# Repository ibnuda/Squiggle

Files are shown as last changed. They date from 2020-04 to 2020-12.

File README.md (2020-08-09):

# Squiggle Keyboard

It's a keyboard family which based on my circumstances, preferences, and
observed usages.

Requirements:

- 5 columns per hand.
  My right pinky is almost useless.
- At most 3 keys for each side's thumb row.
  My right thumb key is almost useless.
- No numrow.
  It's harder and more cumbersome to use than a numpad on a layer.
- Split.
  Typing on single flat keyboard hurts my arms in a lot of use cases.
- Symmetric.
  Personal preferences.

This family keyboard repo will not have any of the following features:

- OLED Screen: useless.
- LEDs: useless for me and hurt my eyes.
- Rotary Encoder: useless for me.
- Hotswap: I need a commitment.
- Case for `Low Profile`: defeating the whole purpose of ***LOW*** profile.

## Screenshot

### Standard

- MX and Alps style switches.
- 34 Keys.
- 4x2u thumb keys.
- 2 Promicros.
- TRRS/TRS cable.

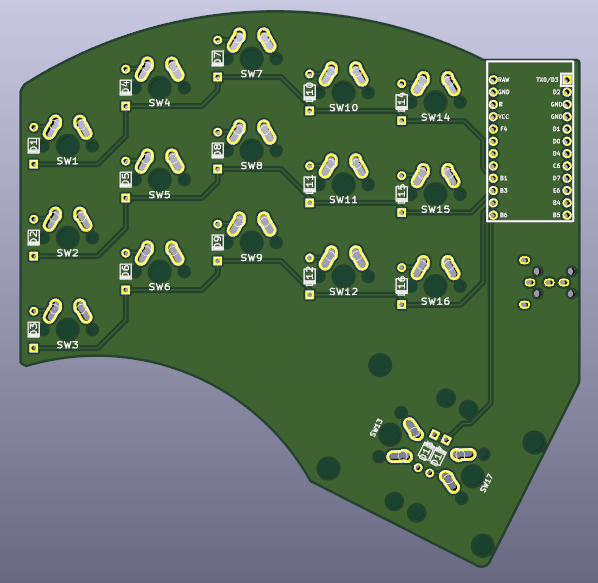
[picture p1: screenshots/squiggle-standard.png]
standard version


### Low Profile

- Dongguan Kaihua Electronics Co., Ltd (originally named Longhua Electronics)'s
  Choc style switches.
- 34 Keys.
- 4x2u thumb keys.
- 2 Promicros.
- TRRS/TRS cable.

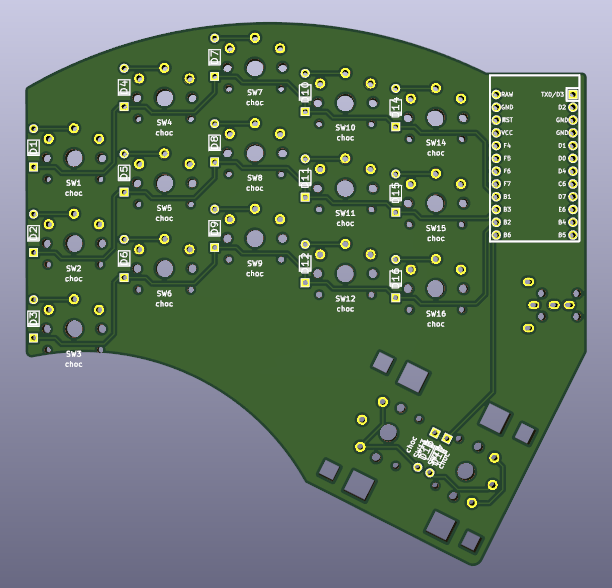
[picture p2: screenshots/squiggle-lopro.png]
low profile


### 36 Keys

- MX and Alps style switches.
- 36 Keys.
- 4x2u+2x1.25u thumb keys.
- 2 Promicros.
- TRRS/TRS cable.

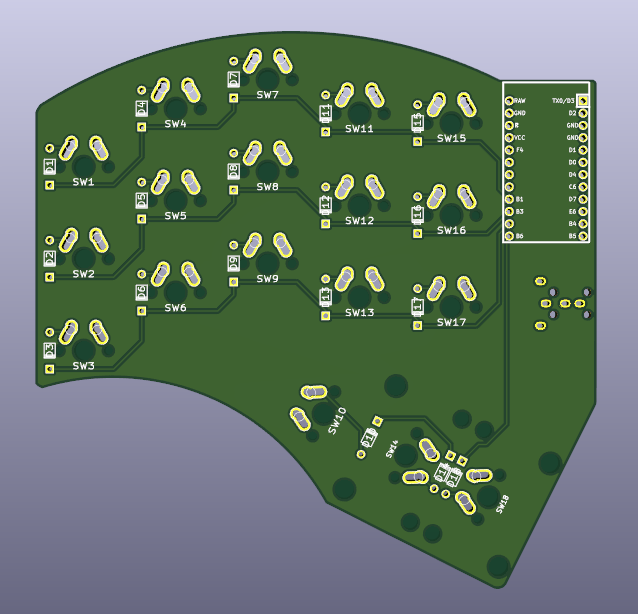
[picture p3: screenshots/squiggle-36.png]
36 keys


### Minimalist

- MX and Alps style switches.
- 34 Keys.
- 4x2u thumb keys.
- 1 Promicros.
- "Amphenol 10 wire" cable.

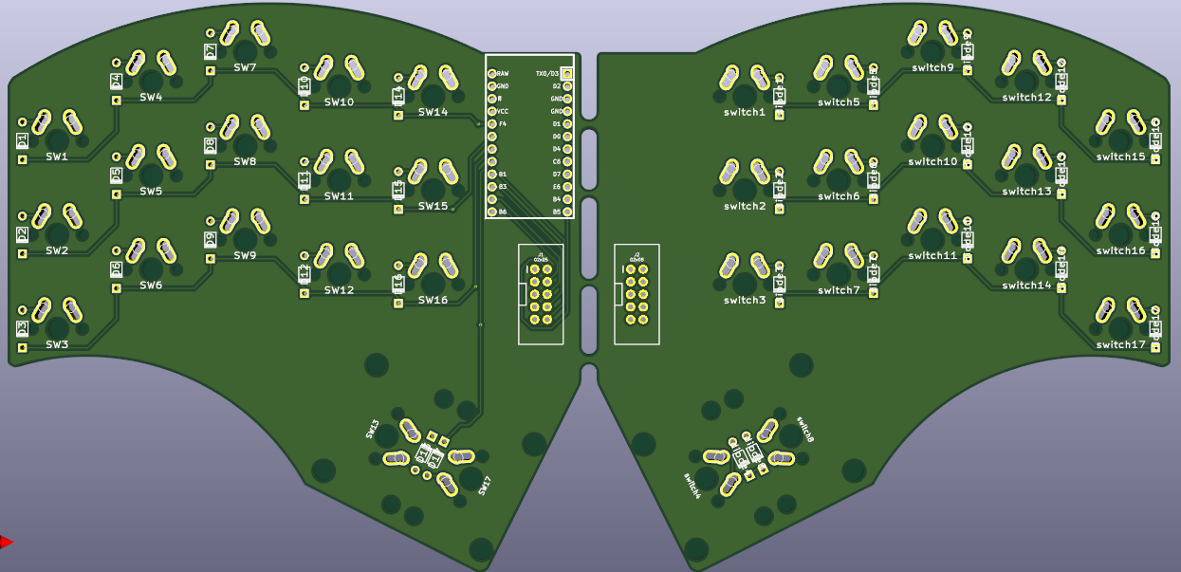
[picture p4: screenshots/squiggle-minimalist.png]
minimalist


### Goldberg

(Because it's more complex than necessary. It's just a damn keyboard.)

- MX and Alps style switches.
- 34 - 38 Keys.
- 4x2u or 8x1u thumb keys. (or anything in between)
- 2 Promicros.
- TRRS/TRS cable.

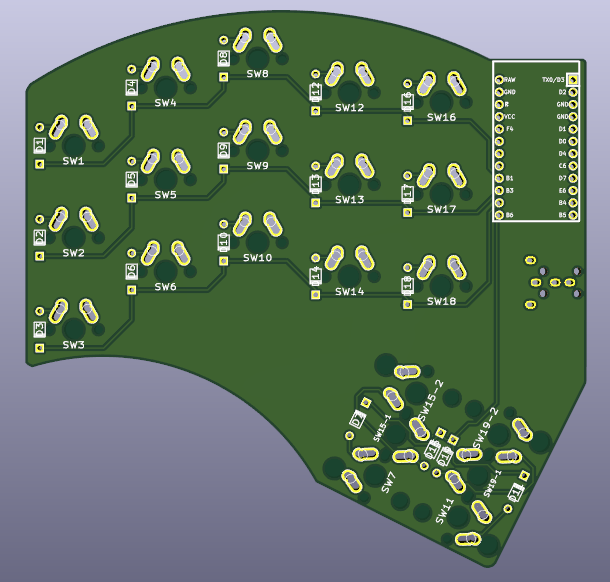
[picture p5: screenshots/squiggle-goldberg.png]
goldberg


## Confirmed Working PCBs

### Standard

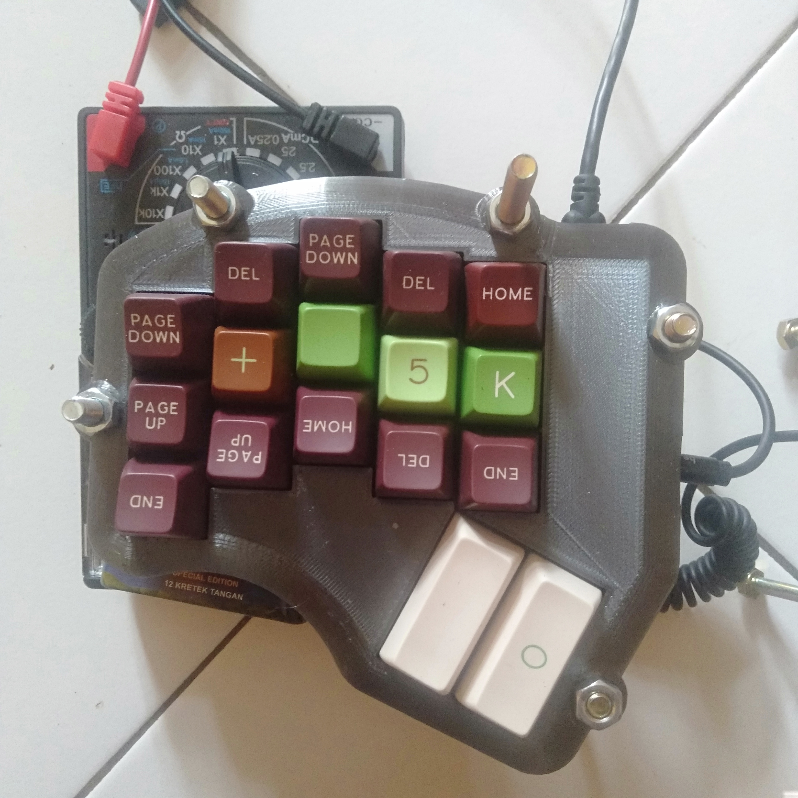
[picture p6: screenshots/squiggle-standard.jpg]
standard


Example firmware: [QMK's master branch](https://github.com/qmk/qmk_firmware/tree/master/keyboards/squiggle/keymaps/rick)

### Goldberg

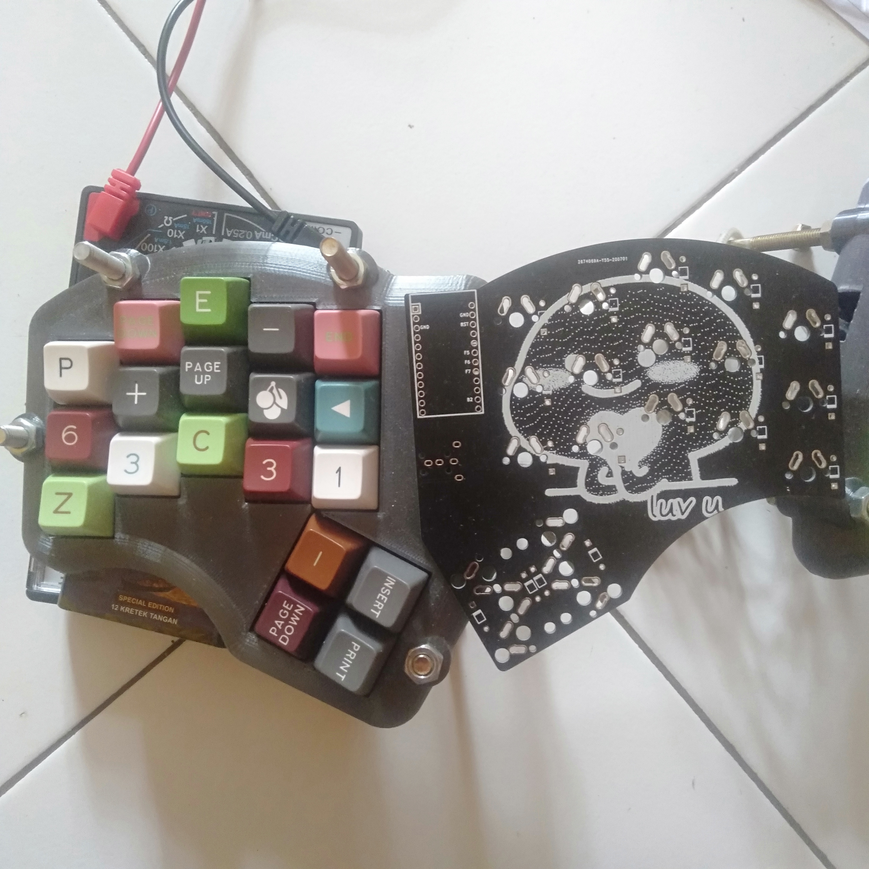
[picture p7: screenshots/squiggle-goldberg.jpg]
goldberg


Example firmware: [QMK's master branch](https://github.com/qmk/qmk_firmware/tree/master/keyboards/squiggle/keymaps/rick-complicated)

### Low Profile

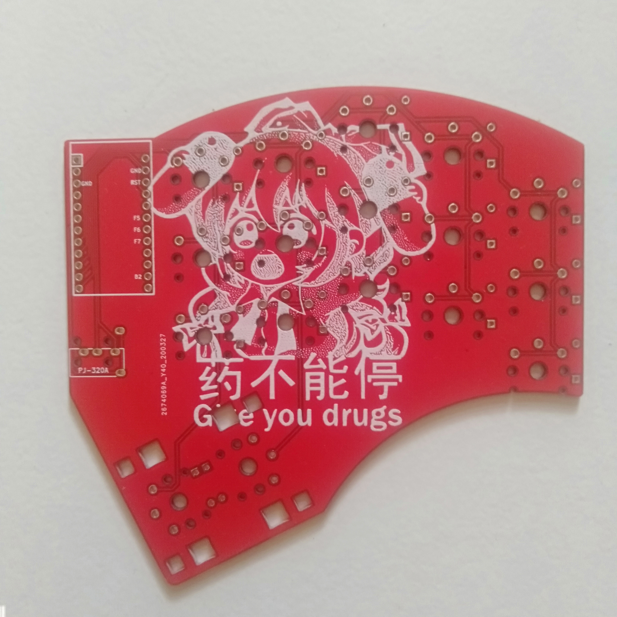
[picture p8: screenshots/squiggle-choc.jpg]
choc


Example firmware: [QMK's master branch](https://github.com/qmk/qmk_firmware/tree/master/keyboards/squiggle/keymaps/rick)

### Minimalist

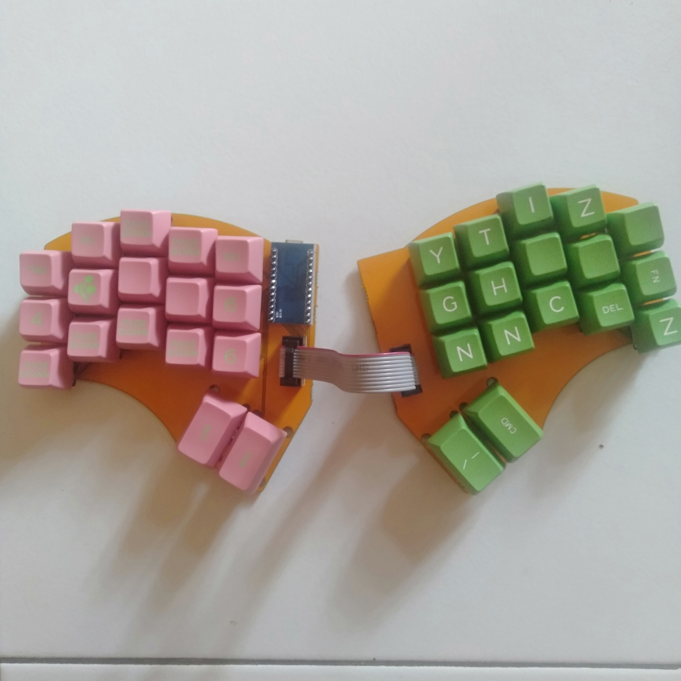
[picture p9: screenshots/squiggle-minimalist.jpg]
minimalist


Example firmware: [Ibnuda's fork](https://github.com/ibnuda/qmk_firmware/tree/squiggle-minimalist/keyboards/squiggle_minimalist/keymaps/rick)

## Disclaimer

I haven't printed some of it. But, theoretically, they should just work.
Oh, if things go wrong, I won't take any responisibilities.

## Additional Note

Any files with `mokou_*.kicad_mod` in `libs/footprints` are made by [Jokan Hiyou](https://twitter.com/jokanhiyou)
and belong to hers.
I just dither them and made them kicad footprints.

## License

GPLv3.

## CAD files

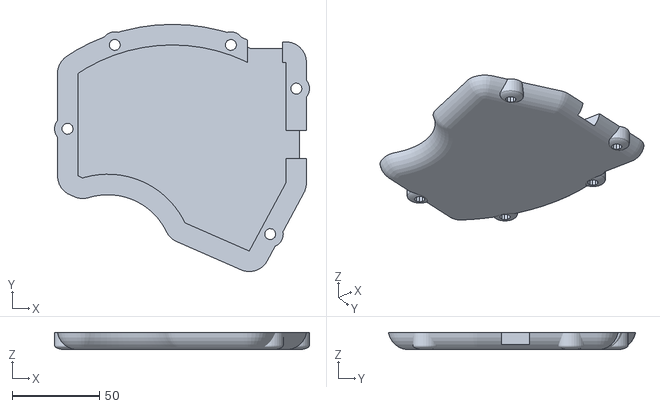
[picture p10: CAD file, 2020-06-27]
plates/fat-bottom.stl
146.0 x 141.5 x 9.93

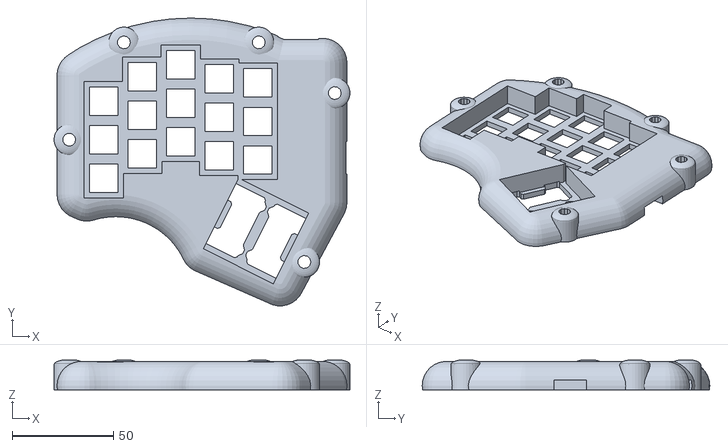
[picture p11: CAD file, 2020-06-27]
plates/fat-top.stl
146.0 x 141.9 x 14.8

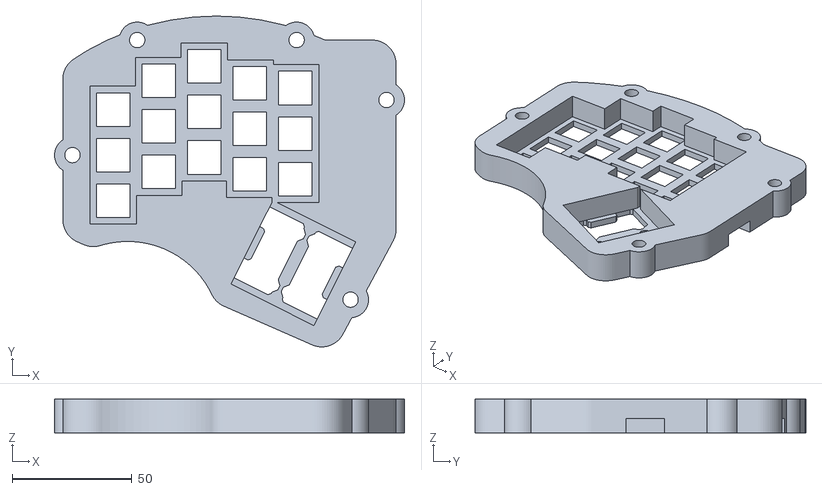
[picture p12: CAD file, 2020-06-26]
plates/another-case-switch-top.stl
146.0 x 138.0 x 14.0

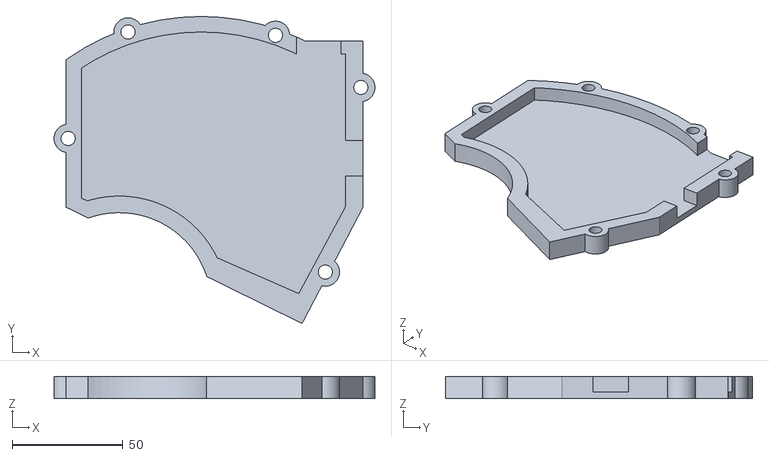
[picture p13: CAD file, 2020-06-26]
plates/case-bottom-middle.stl
144.8 x 138.5 x 10.0

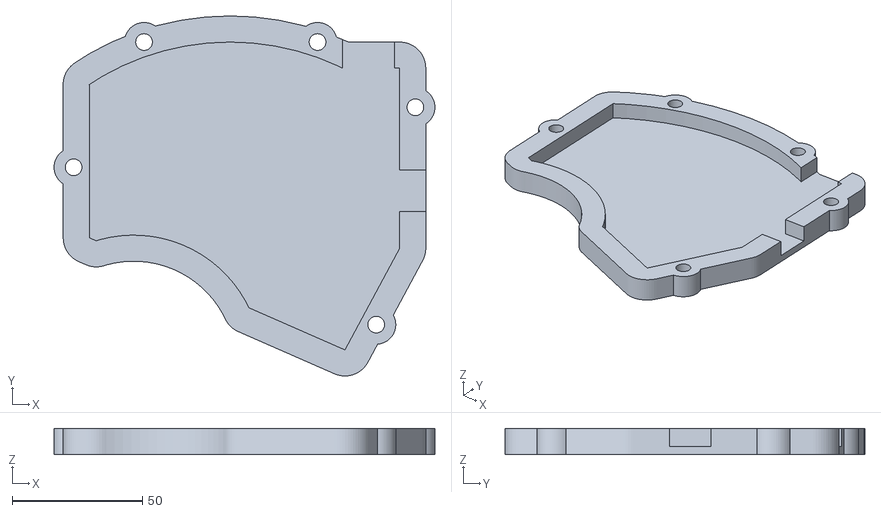
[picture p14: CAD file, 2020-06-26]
plates/another-case-bottom-middle.stl
146.0 x 138.0 x 10.0

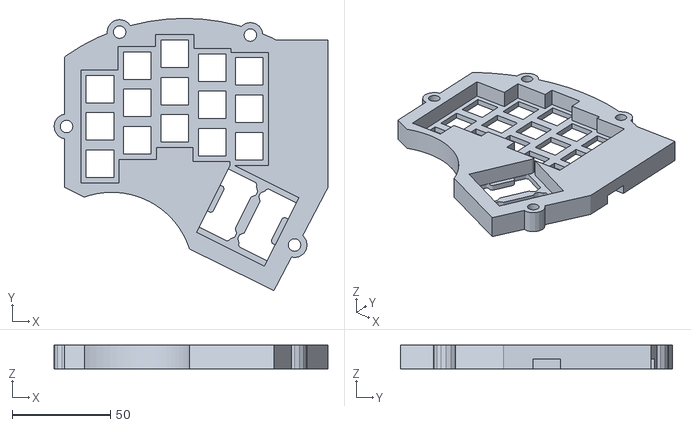
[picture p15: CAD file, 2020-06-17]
plates/case-top-switch.stl
139.4 x 138.5 x 12.0

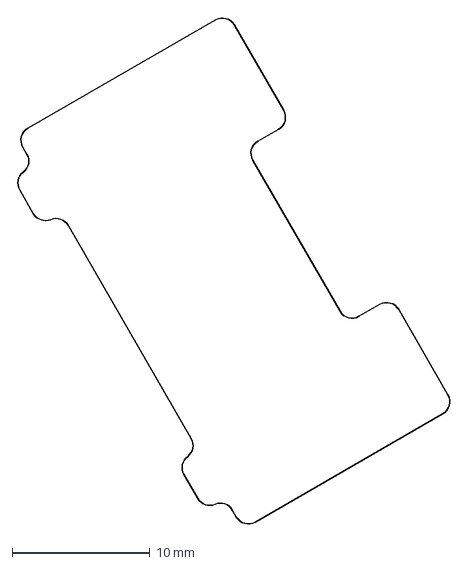
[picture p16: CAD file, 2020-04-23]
plates/2u-cutout.dxf
31.6 x 37.0 mm

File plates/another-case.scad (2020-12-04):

include <common.scad>;

$fn = 60;

bottom_thickness = 3;
middle_thickness = 8;
switch_thickness = 3;
top_thickness = 7;

use_tenting_screws = true;

is_36 = false;

is_case = true;

is_goldberg = false;

is_high = false;

module
bottom_plate()
{
    difference()
    {
        union()
        {
            offset(r = 10) shape_of_pcb();
            if (use_tenting_screws) {
                for (i = [0:len(tenting_screw_positions) - 1]) {
                    translate(tenting_screw_positions[i]) tenting_wing();
                }
            }
        }
        if (use_tenting_screws) {
            for (i = [0:len(tenting_screw_positions) - 1]) {
                translate(tenting_screw_positions[i]) tenting_hole();
            }
        } else {
            for (i = [0:len(tightening_screw_positions) - 1]) {
                translate(tightening_screw_positions[i]) tightening_hole();
            }
        }
    }
}

module
middle_plate()
{
    difference()
    {
        bottom_plate();
        shape_of_pcb();
        // promicro_trrs_space();
        white_space();
    }
}

module upper_plate(hole_width, is_switch_plate = true)
{
    difference()
    {
        bottom_plate();
        alpha_holes(hole_width);
        thumb_hole(96.6, -98.7, 153.4, is_switch_plate, hole_width, is_goldberg);
        thumb_hole(113.7, -107.3, -26.6, is_switch_plate, hole_width, is_goldberg);
        if (is_switch_plate)
        {
            // promicro_trrs_space();
            white_space();
        }
        if (is_36)
        {
            inner_thumb_hole(hole_width);
        }
    }
}

if (is_case) {
    translate([ 150, 0, 0 ]) color([ 0.4, 0.3, 0.2 ])
    {
        // linear_extrude(height = bottom_thickness) { bottom_plate(); }
    }
    translate([ 150, 0, bottom_thickness ]) color([ 0.2, 0.3, 0.2 ])
    {
        linear_extrude(height = middle_thickness) { middle_plate(); }
    }
    translate([ 0, 0, 0 ]) color([ 0.3, 0.3, 0.3 ])
    {
        // linear_extrude(height = switch_thickness) { upper_plate(14, true); }
    }
    if (is_high) {
        difference()
        {
            translate([ 0, 0, switch_thickness ]) color([ 0.5, 0.5, 0.5 ])
            {
                linear_extrude(height = top_thickness)
                {
                    upper_plate(19.5, false);
                }
            }
            translate([ 0, 0, switch_thickness ]) linear_extrude(height = 3)
            {
                promicro_trrs_space();
            }
        }
    }
} else {
    // translate([ 150, 0, 3 ]) color([ 0.2, 0.2, 0.2 ]) bottom_plate();
    // translate([ 0, 140, 3 ]) color([ 0.2, 0.2, 0.2 ]) middle_plate();
    translate([ 0, 0, 6 ]) color([ 0.2, 0.2, 0.9 ]) upper_plate(14, true);
}

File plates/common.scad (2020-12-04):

tenting_screw_positions =
    [ [ 129, -118.3 ], [ 40, -10 ], [ 106.5, -10 ], [ 13, -58 ]/*, [ 144, -35 ]*/ ];

tightening_screw_positions = [
    [ 17.5, -26, 0 ],
    [ 18.5, -88, 0 ],
    [ 81.0, -116, 0 ],
    [ 118.5, -132.5, 0 ],
    [ 139, -88.5, 0 ],
    [ 140, -56.5, 0 ],
    [ 140, -20.5, 0 ],
    [ 112.5, -17.2, 0 ],
    [ 71, -8.6, 0 ]
];

stagger = [ -39, -27, -21, -28, -30 ];

module sector(radius, angles, fn = 60)
{
    r = radius / cos(180 / fn);
    step = -360 / fn;

    points = concat(
        [[ 0, 0 ]],
        [for (a = [angles[0]:step:angles[1] - 360])[r * cos(a), r * sin(a)]],
        [[r * cos(angles[1]), r * sin(angles[1])]]);

    difference()
    {
        circle(radius, $fn = fn);
        polygon(points);
    }
}

module arc(radius, angles, width = 1, fn = 60)
{
    difference()
    {
        sector(radius + width, angles, fn);
        sector(radius, angles, fn);
    }
}

module
tenting_wing()
{
    circle(r = 7.5);
}

module
tenting_hole()
{
    circle(r = 3.2);
}

module
tightening_hole()
{
    circle(r = 1.2);
}

module
white_space()
{
    polygon(points=[
        [ 116, -5 ],
        [ 116, -77.5 ],
        [ 150, -94.5 ],
        [ 150, -10 ]
    ]);
}

module
promicro_space()
{
    // promicro space.
    polygon(points = [
        [ 116, -5 ],
        [ 136, -5 ],
        [ 136, -56 ],
        [ 116, -56 ],
    ]);
}

module
trrs_space()
{
    polygon(points = [
        [ 155, -75 ],
        [ 155, -59 ],
        [ 122, -59 ],
        [ 122, -75 ],
    ]);

}

module
idc_space()
{
    polygon(points = [
        [ 122, -59 ],
        [ 133, -59 ],
        [ 133, -81 ],
        [ 122, -81 ],
    ]);
}

module alpha_holes(width = 14)
{
    for (j = [0:2]) {
        for (i = [0:4]) {
            translate([ (30 + i * 19), (stagger[i] - j * 19), 0 ])
            {
                square(size = [ width, width ], center = true);
            }
        }
    }
}

module
inner_thumb_hole(width = 14)
{
    translate([ 79.57, -90.06 ])
    {
        rotate([ 0, 0, 63.4 ])
        {
            square(size = [ width, width ], center = true);
        }
    }
}

module
thumb_imported_from_file()
{
    translate([ 7, -6.3, 0 ])
    {
        rotate([ 0, 0, -30 ]) { import("2u-cutout.dxf"); }
    }
}

module
thumb_two_u()
{
    union()
    {
        translate([ 0, 9.5, 0 ]) { square(size = [ 14, 14 ], center = true); }
        translate([ 0, -9.5, 0 ]) { square(size = [ 14, 14 ], center = true); }
    }
}

module thumb_hole(x, y, rotation, is_switch_plate = true, hole_width = 14, is_goldberg = false)
{
    translate([ x, y, 0 ])
    {
        rotate([ 0, 0, rotation ])
        {
            if (is_switch_plate) {
                if (is_goldberg) {
                    thumb_two_u();
                } else {
                    thumb_imported_from_file();
                }
            } else {
                square(size = [ hole_width, hole_width * 2 ], center = true);
            };
        }
    }
}

module
shape_of_pcb()
{
    upper_angles = [ 63.7, 123.5 ];
    lower_angles = [ 15, 112 ];
    difference()
    {
        union()
        {
            translate([ 73, -108 ]) sector(98, upper_angles, 72);
            polygon(points = [
                [ 19, -26.4 ],
                [ 19, -85 ],
                [ 117, -128 ],
                [ 138, -89 ],
                [ 138, -20 ],
                [ 116, -20 ],
            ]);
        }
        translate([ 36, -133 ]) sector(49, lower_angles, 75);
    }
}

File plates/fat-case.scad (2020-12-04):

include <common.scad>

// when you don't use 2x2u for the thumbkey.
is_goldberg = false;
// when you use the minimalist variant.
is_minimalist = true;

bottom_plate_thickness = 5;
pcb_space_thickness = is_goldberg ? 4 : 6;
bottom_pcb_thickness = bottom_plate_thickness + pcb_space_thickness;
switch_plate_thickness = is_goldberg ? 5 : 3;
bottom_pcb_switch_thickness = bottom_pcb_thickness + switch_plate_thickness;

promicro_trrs_height = 12;
idc_space_height = 25;

movement = is_goldberg ? 3 : 5;

module
almost_flat_sphere()
{
    resize([ 15, 15, 4.5 ]) translate([ 0, 0, -75 ]) sphere(r = 75);
}

module
tenting_cylinder()
{
    hull()
    {
        translate([ 0, 0, 25 ]) almost_flat_sphere();
        translate([ 0, 0, 4 ]) almost_flat_sphere();
    }
}

module
base_case()
{
    difference()
    {
        union()
        {
            minkowski()
            {
                translate([ 0, 0, 12 ]) sphere(r = 12);
                linear_extrude(height = 0.1) shape_of_pcb();
            }
            for (i = [0:len(tenting_screw_positions) - 1]) {
                translate(tenting_screw_positions[i]) tenting_cylinder();
            }
        }

        for (i = [0:len(tenting_screw_positions) - 1]) {
            translate([ 0, 0, -1 ]) linear_extrude(height = (12 * 2.5))
                translate(tenting_screw_positions[i]) tenting_hole();
        }
    }
}

module case ()
{
    difference()
    {
        base_case();
        translate([ 0, 0, bottom_plate_thickness ]) linear_extrude(height = pcb_space_thickness) shape_of_pcb();
        translate([ 0, 0, bottom_plate_thickness ]) linear_extrude(height = promicro_trrs_height) promicro_space();
        if (is_minimalist) {
            translate([ 0, 0, bottom_plate_thickness ]) linear_extrude(height = idc_space_height) idc_space();
        } else {
            translate([ 0, 0, bottom_plate_thickness ]) linear_extrude(height = promicro_trrs_height) trrs_space();
        }
        translate([ 0, 0, bottom_pcb_thickness ]) linear_extrude(height = 5) alpha_holes(14);
        translate([ 0, 0, bottom_pcb_thickness ]) linear_extrude(height = 5) thumb_hole(96.6, -98.7, 153.4, true, 14, is_goldberg);
        translate([ 0, 0, bottom_pcb_thickness ]) linear_extrude(height = 5) thumb_hole(113.7, -107.3, -26.6, true, 14, is_goldberg);
        translate([ 0, 0, bottom_pcb_switch_thickness ]) linear_extrude(height = 23) alpha_holes(19.5);
        translate([ 0, 0, bottom_pcb_switch_thickness ]) linear_extrude(height = 23) thumb_hole(96.6, -98.7, 153.4, false, 19.5, is_goldberg);
        translate([ 0, 0, bottom_pcb_switch_thickness ]) linear_extrude(height = 23) thumb_hole(113.7, -107.3, -26.6, false, 19.5, is_goldberg);
    }
}

// bottom case.
intersection()
{
    case();
    translate([150, -150, movement]) {
        cube(size = [400, 400, 12 ], center = true);
    }
}

// top case.
translate([160, 0, -bottom_pcb_thickness]) {
    difference()
    {
        color("navy")case();
        translate([150, -150, movement]) {
            cube(size = [400, 400, 12 ], center = true);
        }
    }
}

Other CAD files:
plates/standard-case.scad

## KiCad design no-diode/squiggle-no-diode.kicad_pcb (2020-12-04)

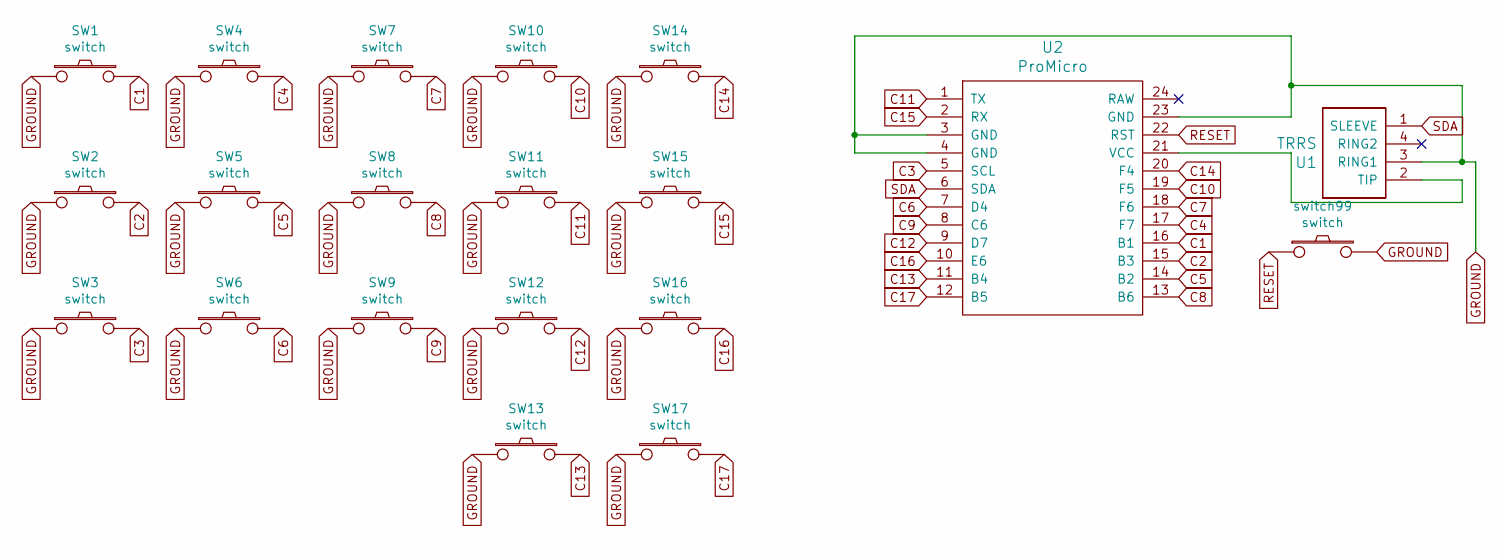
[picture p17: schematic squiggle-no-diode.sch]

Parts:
SW1, SW2, SW3, SW4, SW5, SW6, SW7, SW8, SW9, SW10, SW11, SW12, SW14, SW15, SW16: switch; 1u-dual
SW13, SW17: switch; 2u-dual
U1: TRRS; trrs
U2: ProMicro; promicro
switch99: switch; SW_PUSH_6mm_H4.3mm

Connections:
C1: SW1.2, U2.16 (B1)
C2: SW2.2, U2.15 (B3)
C3: SW3.2, U2.5 (SCL)
C4: SW4.2, U2.17 (F7)
C5: SW5.2, U2.14 (B2)
C6: SW6.2, U2.7 (D4)
C7: SW7.2, U2.18 (F6)
C8: SW8.2, U2.13 (B6)
C9: SW9.2, U2.8 (C6)
C10: SW10.2, U2.19 (F5)
C11: SW11.2, U2.1 (TX)
C12: SW12.2, U2.9 (D7)
C13: SW13.2, U2.11 (B4)
C14: SW14.2, U2.20 (F4)
C15: SW15.2, U2.2 (RX)
C16: SW16.2, U2.10 (E6)
C17: SW17.2, U2.12 (B5)
GROUND: SW1.1, SW2.1, SW3.1, SW4.1, SW5.1, SW6.1, SW7.1, SW8.1, SW9.1, SW10.1, SW11.1, SW12.1, SW13.1, SW14.1, SW15.1, SW16.1, SW17.1, U1.3 (RING1), U2.3 (GND), U2.4 (GND), U2.23 (GND), switch99.2
unnamed: U1.2 (TIP), U2.21 (VCC)
RESET: U2.22 (RST), switch99.1
SDA: U1.1 (SLEEVE), U2.6 (SDA)

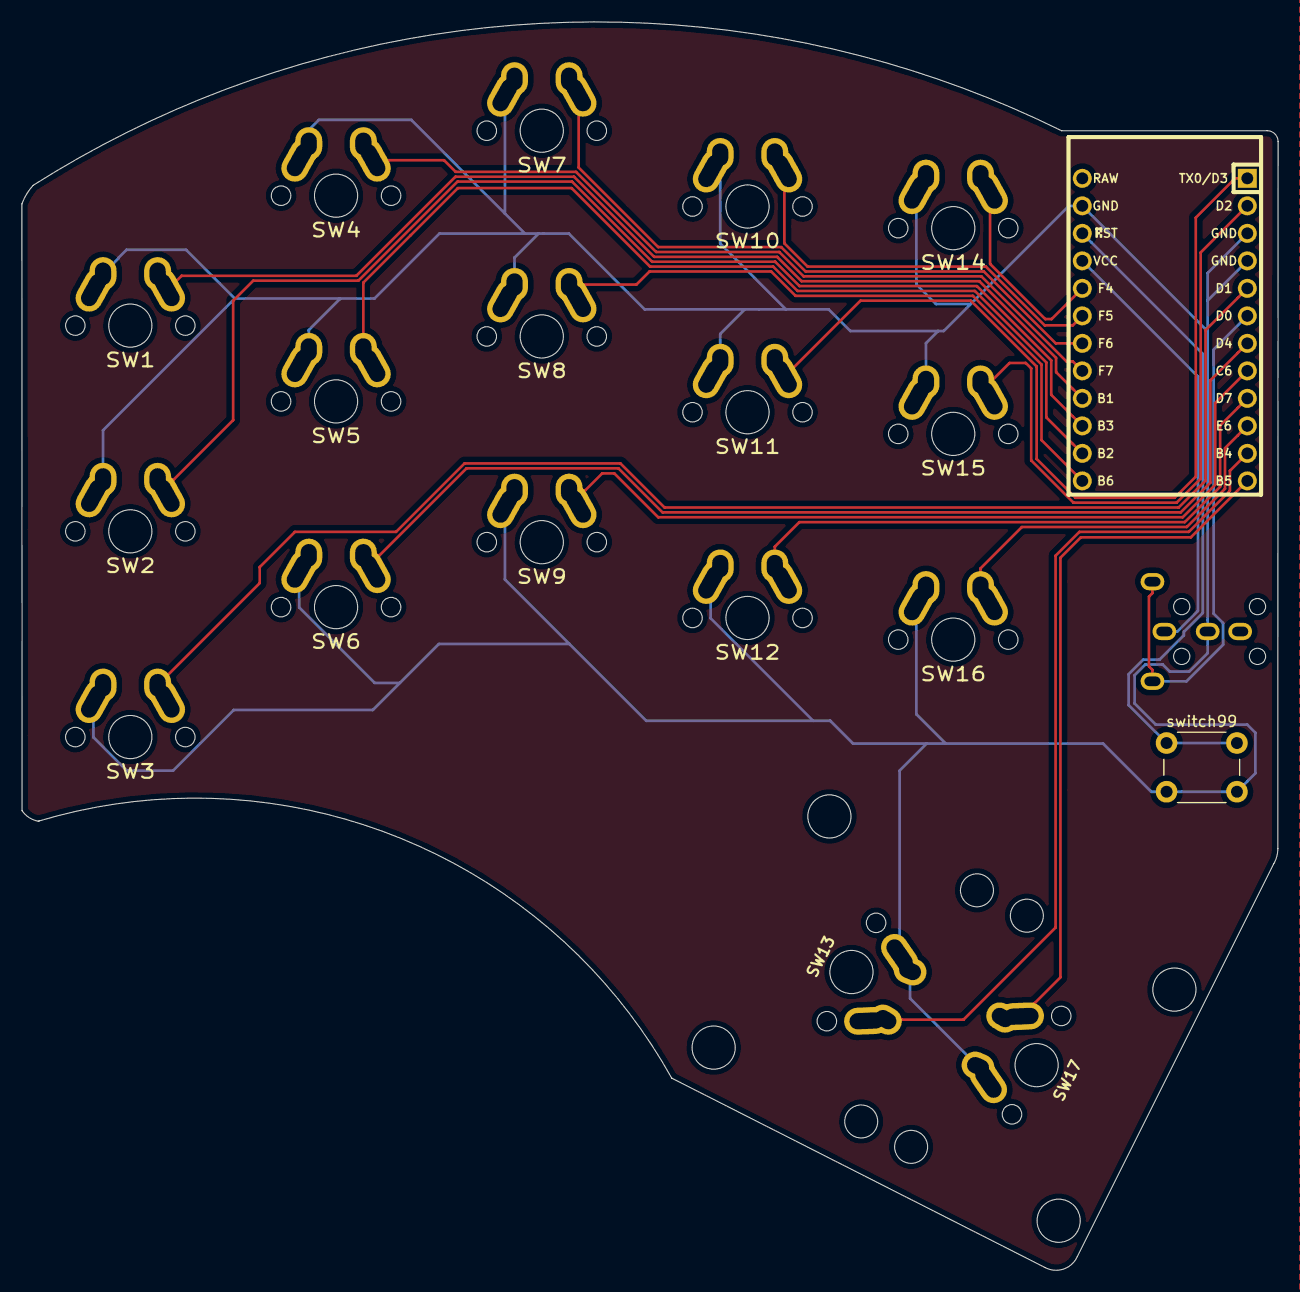
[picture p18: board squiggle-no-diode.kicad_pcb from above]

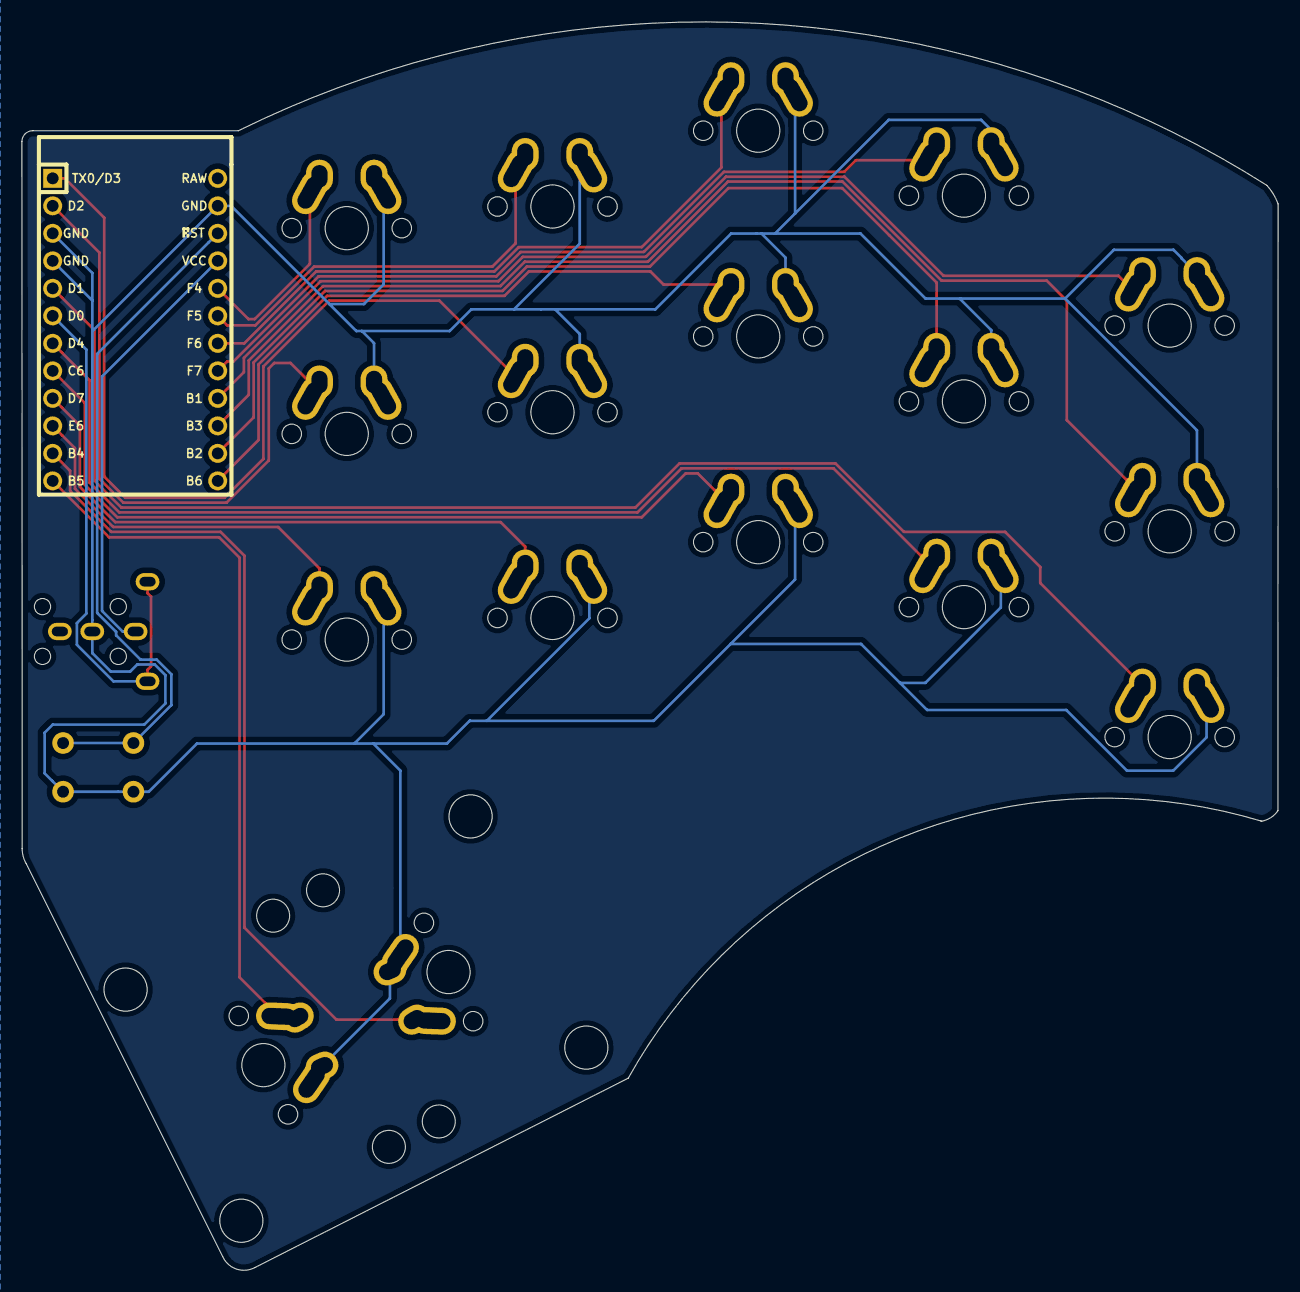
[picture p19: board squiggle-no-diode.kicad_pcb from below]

Board: 2 copper layers, 116.0 x 115.3 mm, 20 parts (2 on the bottom side), 21 nets.

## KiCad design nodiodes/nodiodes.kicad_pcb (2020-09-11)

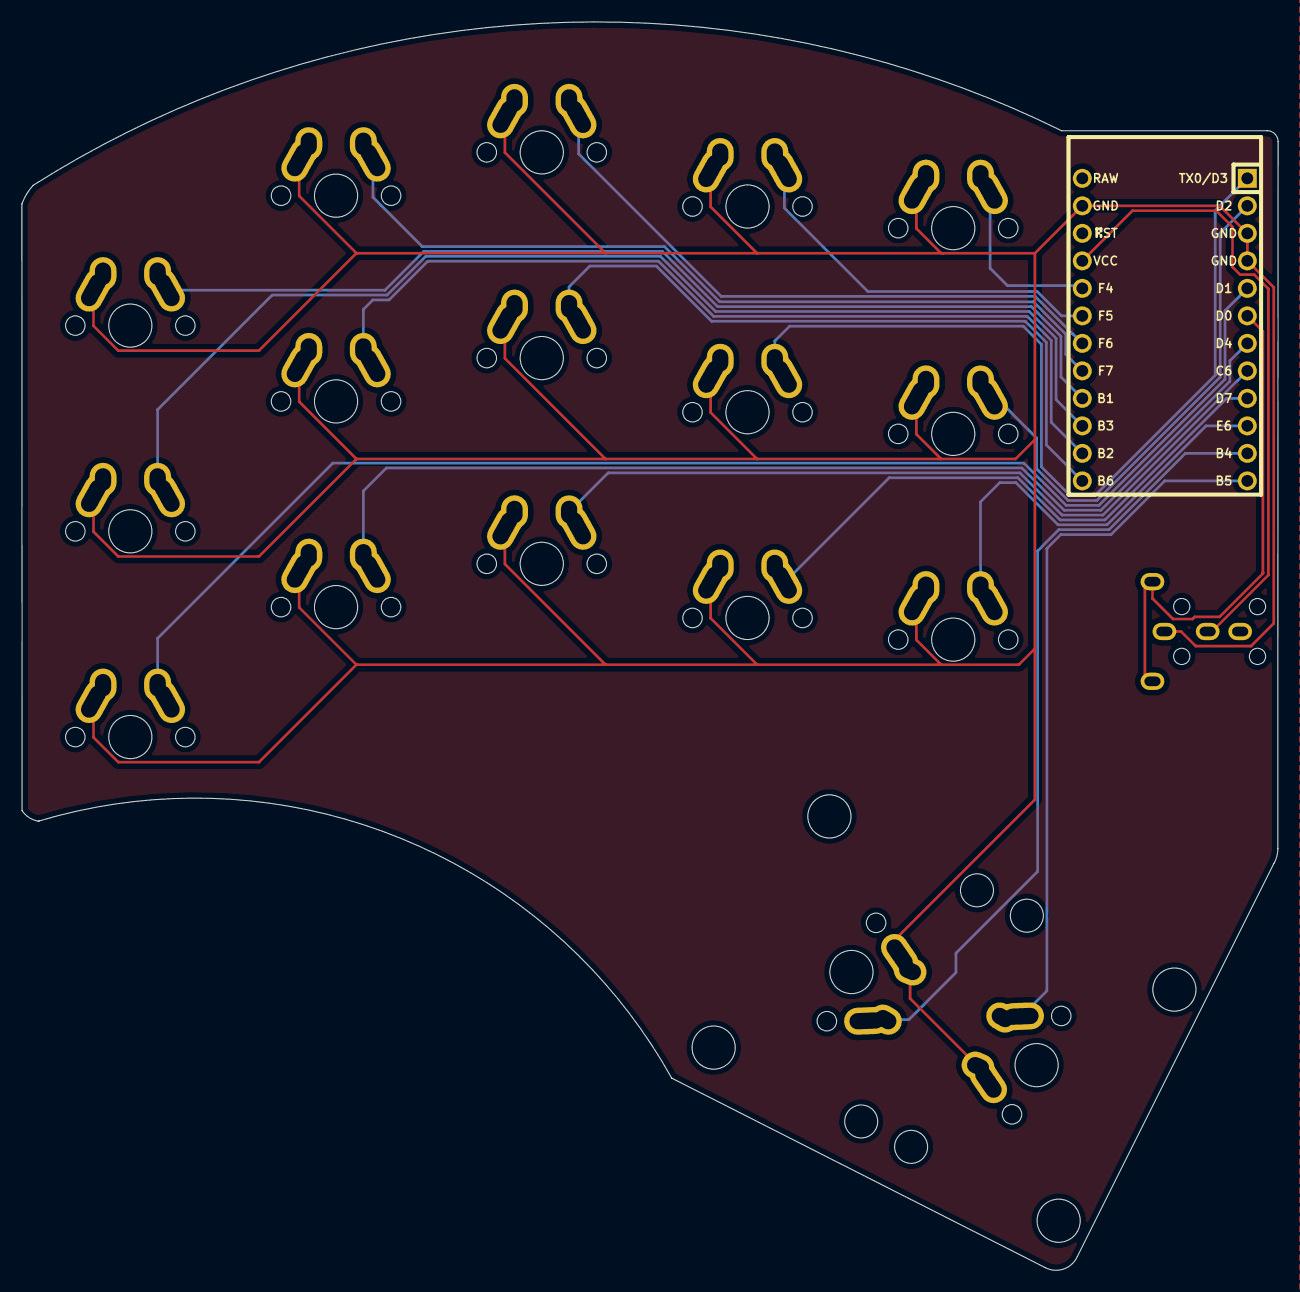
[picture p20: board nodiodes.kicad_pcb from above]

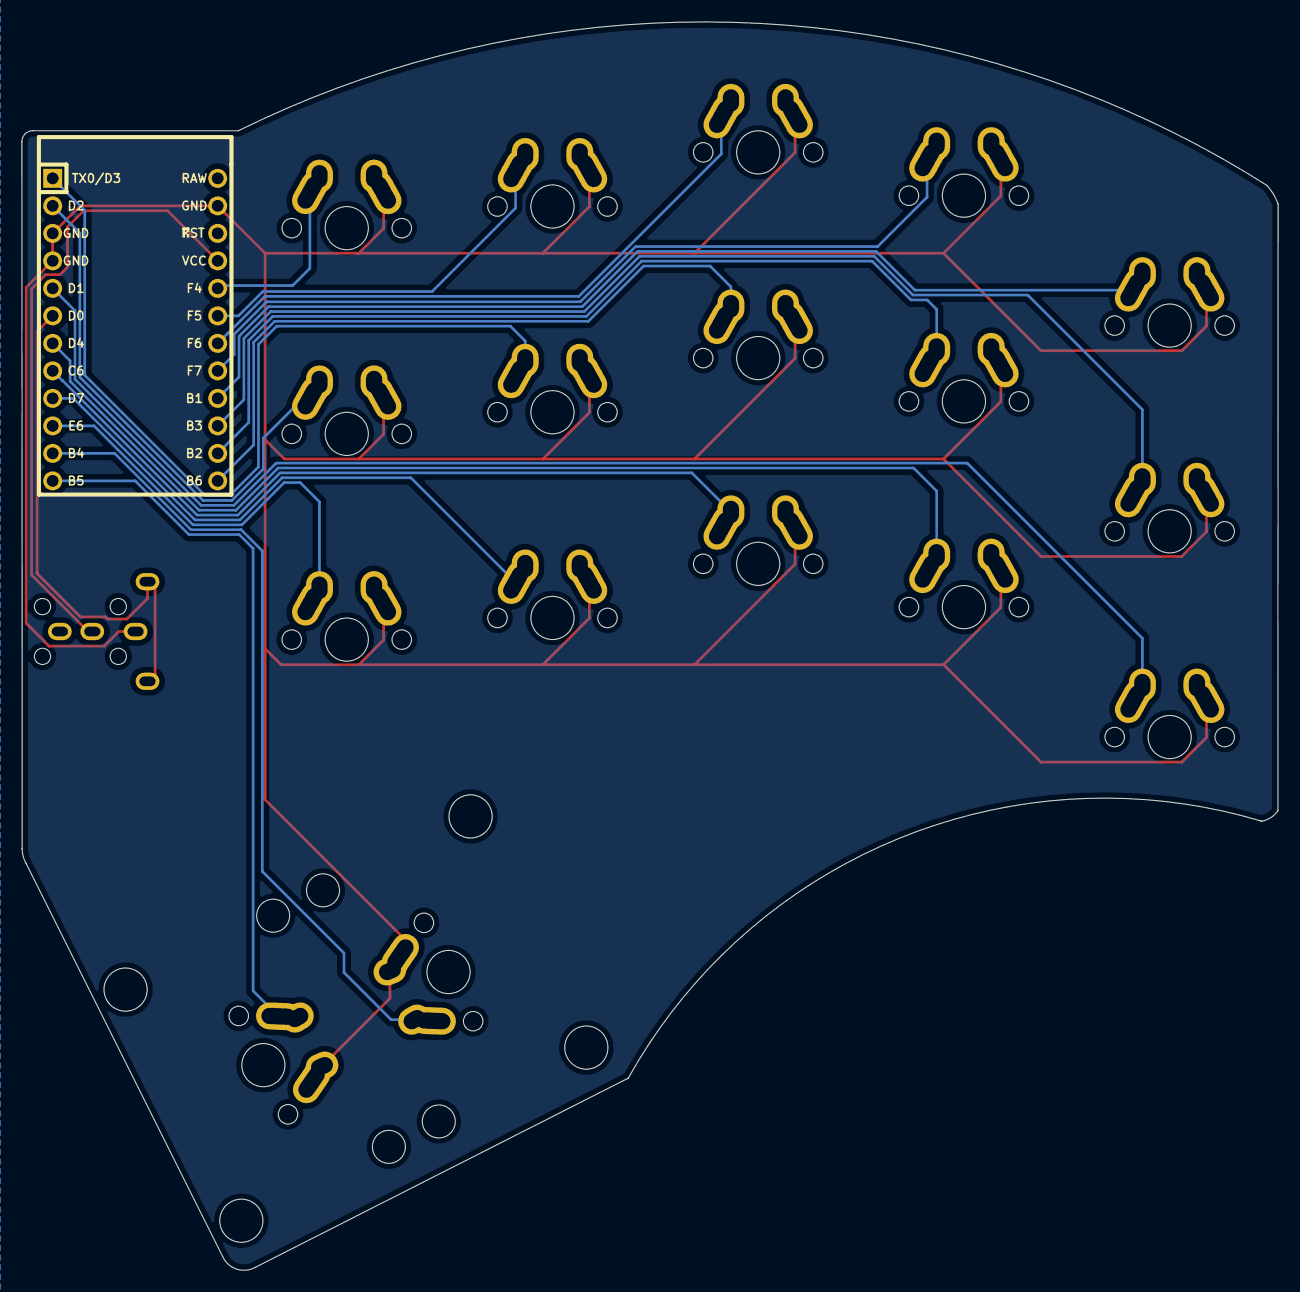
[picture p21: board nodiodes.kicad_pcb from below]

Board: 2 copper layers, 116.0 x 115.3 mm, 19 parts (2 on the bottom side), 20 nets.

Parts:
U1: trrs
U2: promicro
switch1, switch2, switch3, switch4, switch5, switch6, switch7, switch8, switch9, switch10, switch11, switch12, switch13, switch14, switch15: switch; 1u-dual
switch16, switch17: switch; 2u-dual

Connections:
GND: U1.2, U2.3, U2.4, U2.23, switch1.1, switch2.1, switch3.1, switch4.1, switch5.1, switch6.1, switch7.1, switch8.1, switch9.1, switch10.1, switch11.1, switch12.1, switch13.1, switch14.1, switch15.1, switch16.1, switch17.1
I11: U2.19, switch4.2
I12: U2.1, switch9.2
I13: U2.9, switch14.2
I21: U2.20, switch5.2
I22: U2.2, switch10.2
I23: U2.10, switch15.2
M1: U2.18, switch3.2
M2: U2.13, switch8.2
M3: U2.8, switch13.2
P1: U2.16, switch1.2
P2: U2.15, switch6.2
P3: U2.5, switch11.2
R1: U2.17, switch2.2
R2: U2.14, switch7.2
R3: U2.7, switch12.2
SDA: U1.1, U2.6
T1: U2.11, switch16.2
T2: U2.12, switch17.2
VCC: U1.3, U2.21

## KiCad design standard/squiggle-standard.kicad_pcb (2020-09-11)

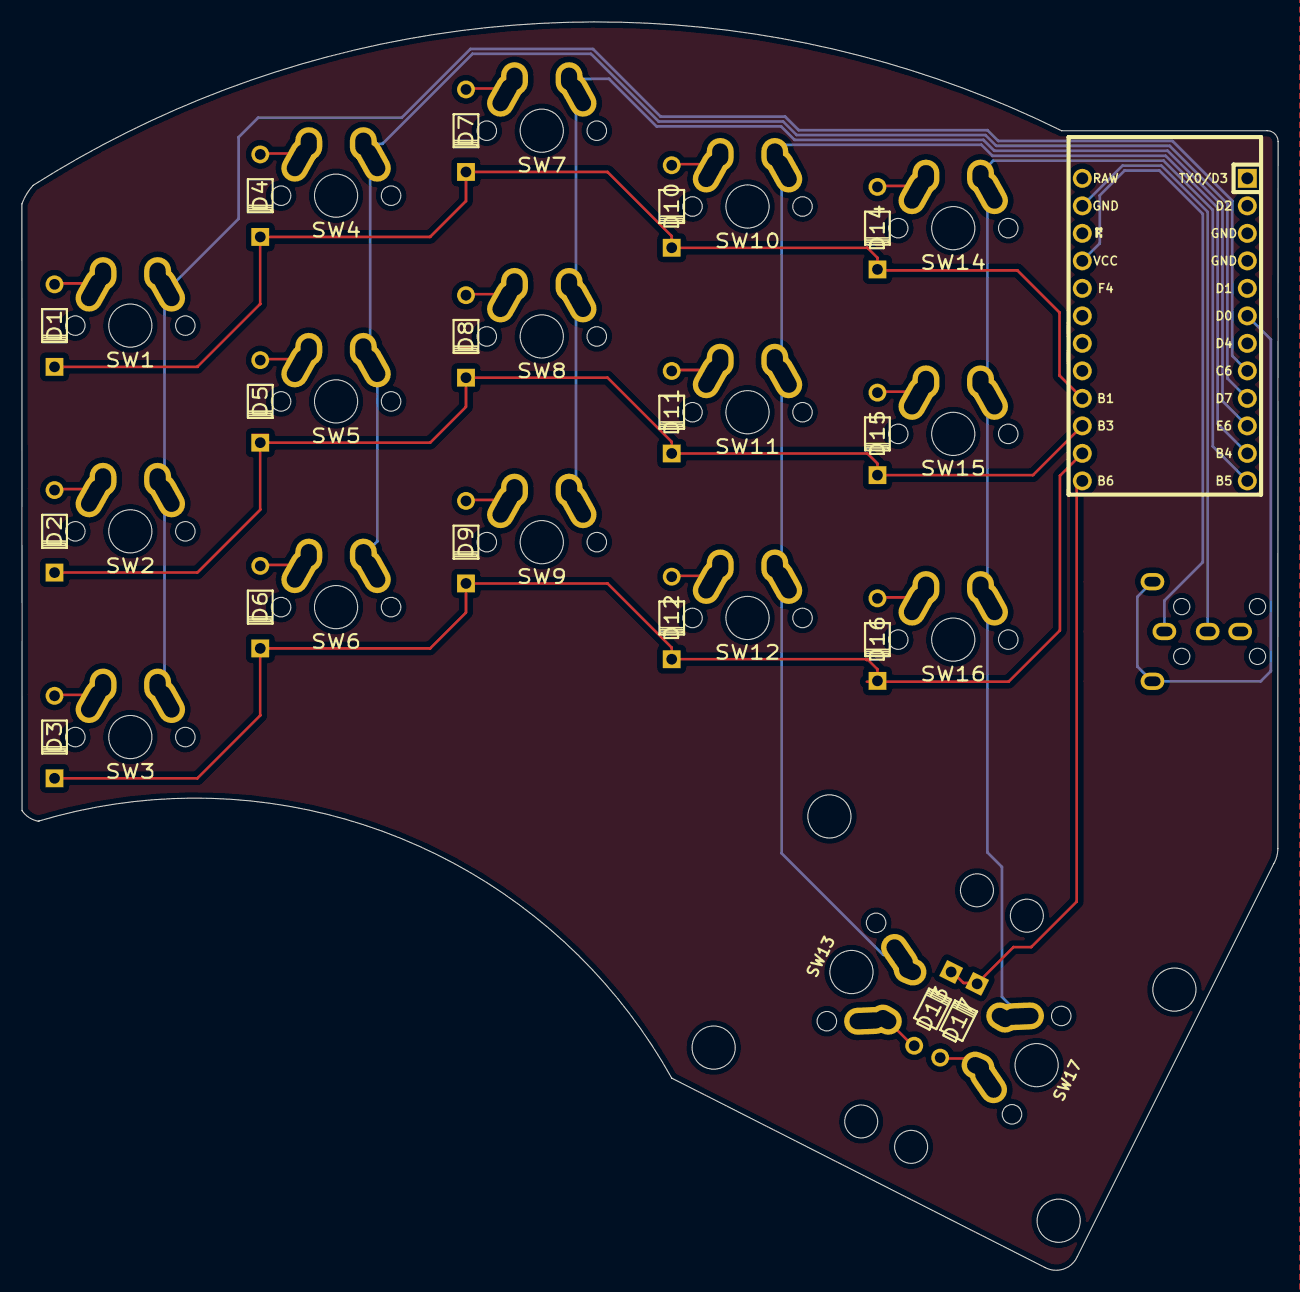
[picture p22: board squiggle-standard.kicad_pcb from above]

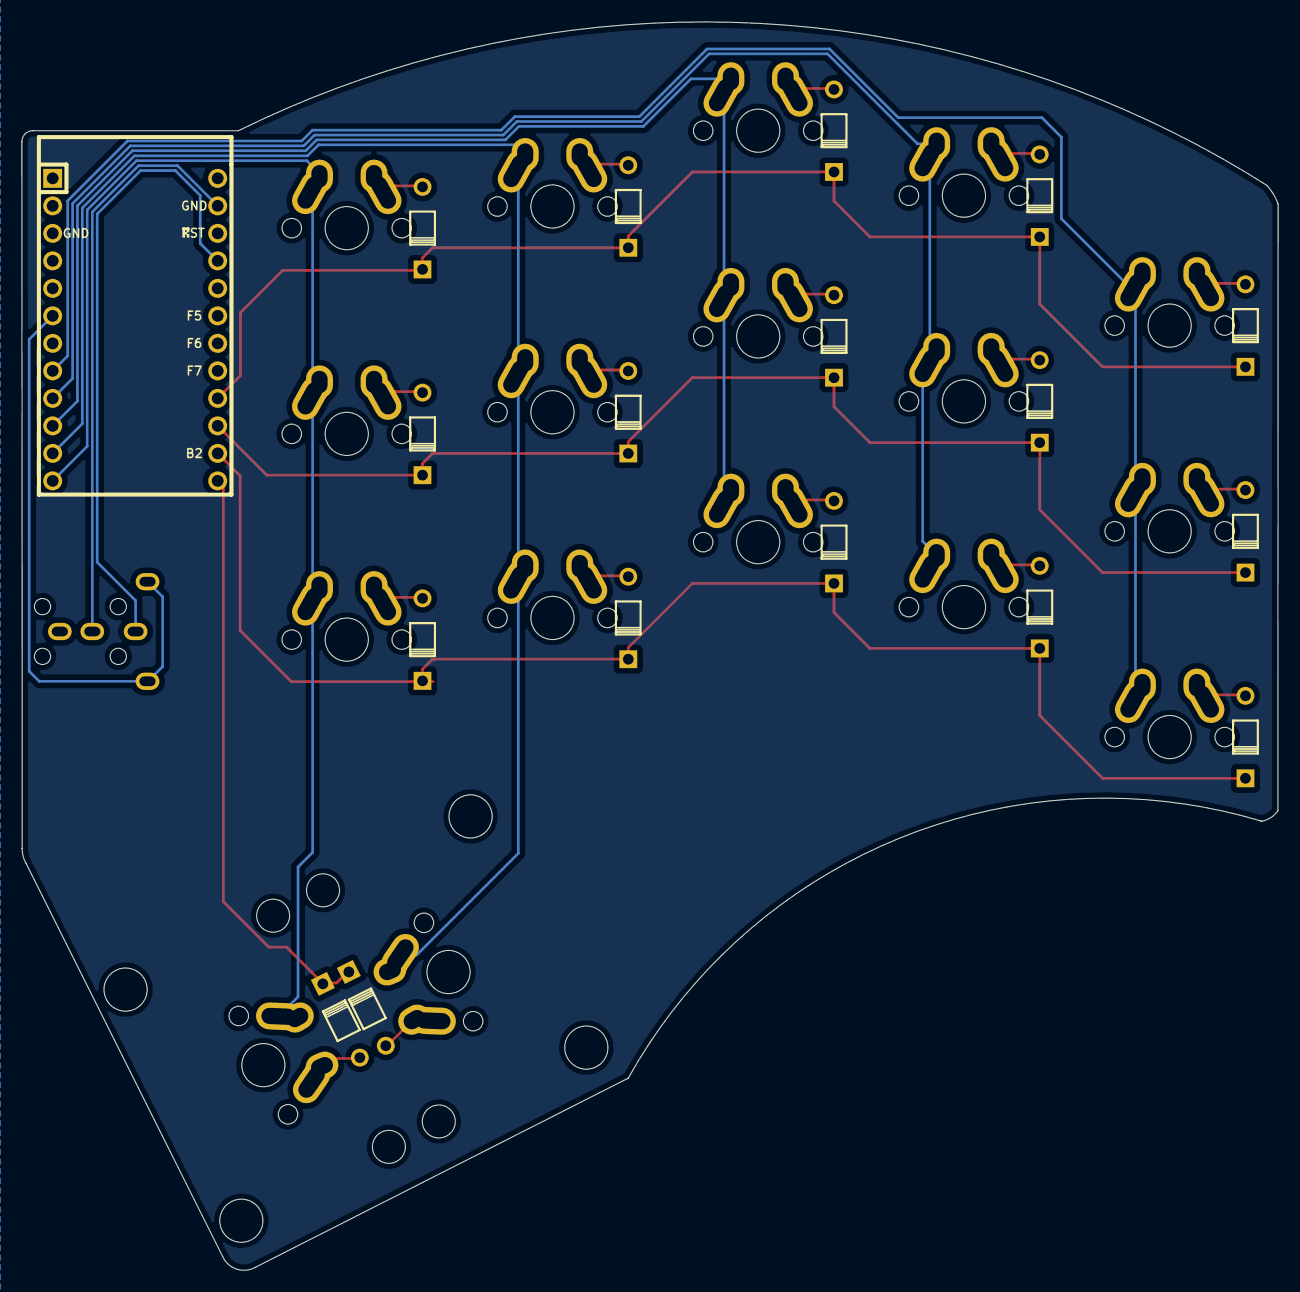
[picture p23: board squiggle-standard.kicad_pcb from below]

Board: 2 copper layers, 116.0 x 115.3 mm, 36 parts (2 on the bottom side), 29 nets.

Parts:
D1, D2, D3, D4, D5, D6, D7, D8, D9, D10, D11, D12, D13, D14, D15, D16, D17: D; diode
SW1, SW2, SW3, SW4, SW5, SW6, SW7, SW8, SW9, SW10, SW11, SW12, SW14, SW15, SW16: switch; 1u-dual
SW13, SW17: switch; 2u-dual
U1: TRRS; trrs
U2: ProMicro; promicro

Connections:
COL0: SW1.2, SW2.2, SW3.2, U2.8
COL1: SW4.2, SW5.2, SW6.2, U2.9
COL2: SW7.2, SW8.2, SW9.2, U2.10
COL3: SW10.2, SW11.2, SW12.2, SW13.1, U2.11
COL4: SW14.2, SW15.2, SW16.2, SW17.2, U2.12
unnamed: D1.2, SW1.1
unnamed: D2.2, SW2.1
unnamed: D3.2, SW3.1
unnamed: D4.2, SW4.1
unnamed: D5.2, SW5.1
unnamed: D6.2, SW6.1
unnamed: D7.2, SW7.1
unnamed: D8.2, SW8.1
unnamed: D9.2, SW9.1
unnamed: D10.2, SW10.1
unnamed: D11.2, SW11.1
unnamed: D12.2, SW12.1
unnamed: D13.2, SW13.2
unnamed: D14.2, SW14.1
unnamed: D15.2, SW15.1
unnamed: D16.2, SW16.1
unnamed: D17.2, SW17.1
unnamed: U1.2, U2.21
unnamed: U1.3, U2.23
ROW0: D1.1, D4.1, D7.1, D10.1, D14.1, U2.16
ROW1: D2.1, D5.1, D8.1, D11.1, D15.1, U2.15
ROW2: D3.1, D6.1, D9.1, D12.1, D16.1, U2.14
ROW3: D13.1, D17.1, U2.13
SDA: U1.1, U2.6

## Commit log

2020-04-23 squiggle mx.
    [2u-cutout.dxf, squiggle-standard.kicad_pcb, squiggle-standard.sch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]
2020-04-23 squiggle 36.
    [squiggle-36.kicad_pcb, squiggle-36.sch, squiggle-lopro.kicad_pcb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]
2020-04-27 finished routing minimalist.
    [squiggle-minimalist.kicad_pcb]
2020-05-17 added stl files for the standard case.
    [squiggle-standard.kicad_pcb, standard-case-bottom.stl, standard-case-switch-middle.stl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]
2020-05-27 changed the screw holes' measurement.
    [standard-case-bottom.stl, standard-case-switch-middle.stl, standard-case.scad]
2020-06-16 useless things.
    [case-bottom-middle.stl, case-top-switch.stl, standard-case-bottom.stl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]
2020-06-17 smoke weed erryday.
    [case-bottom-middle.stl, case-top-switch.stl, standard-case.scad]
2020-06-26 added some things.
    - i really love baldy emojis.
    - another case with nices curves.
    [another-case-bottom-middle.stl, another-case-switch-top.stl, another-case.scad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]
2020-06-27 case using minkowsi function.
    [another-case.scad, common.scad, fat-bottom.stl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]
2020-06-27 softer tenting holder.
    [common.scad, fat-bottom.stl, fat-case.scad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]
2020-07-30 fat-case now have an option to ease model generation.
    [fat-case.scad]
2020-08-01 added some new footprints.
    [squiggle-minimalist.kicad_pcb]
2020-09-11 idk lol.
    [another-case.scad, common.scad, nodiodes.kicad_pcb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]
2020-11-26 no diodes
    without any diodes. as requested by @davidphilipbarr
    [squiggle-no-diode.kicad_pcb, squiggle-no-diode.sch]
2020-11-29 added support for minimalist.
    [common.scad, fat-case.scad]
2020-12-04 i forgot what i did.
    [another-case.scad]
